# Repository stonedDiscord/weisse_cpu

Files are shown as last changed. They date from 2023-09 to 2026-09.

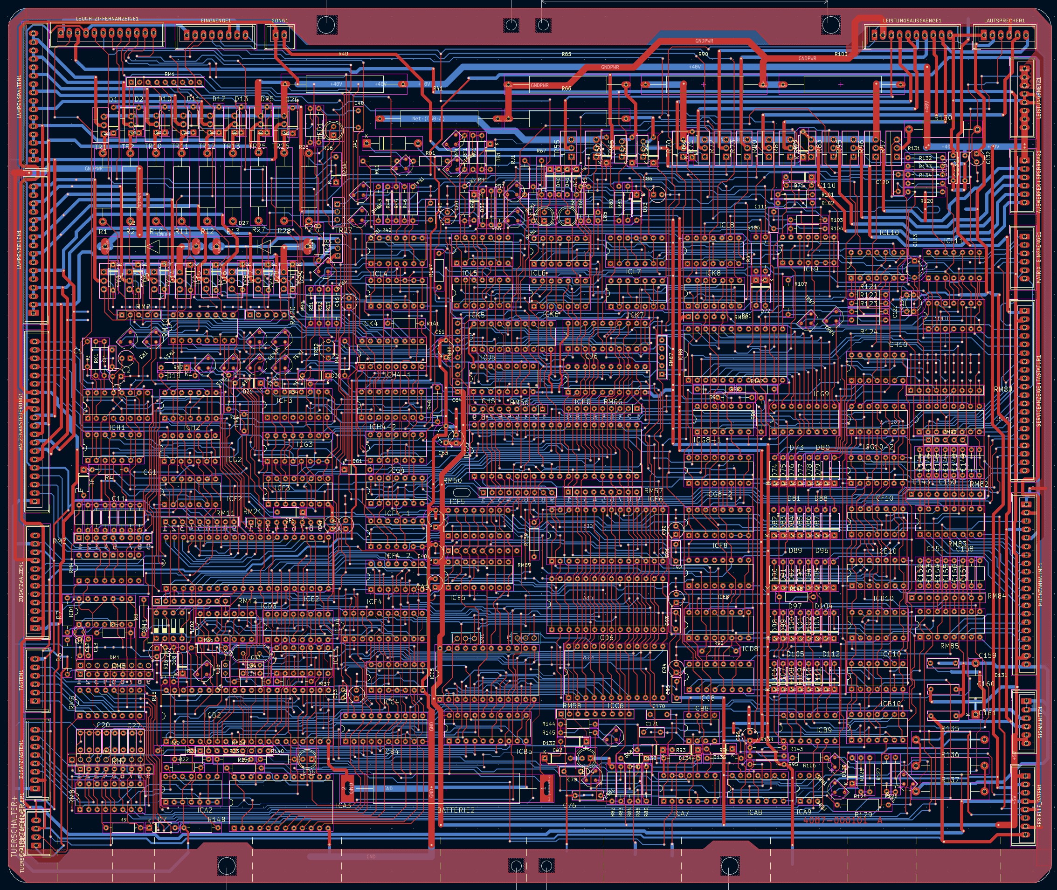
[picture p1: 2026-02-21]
layout_weisse_cpu.jpg

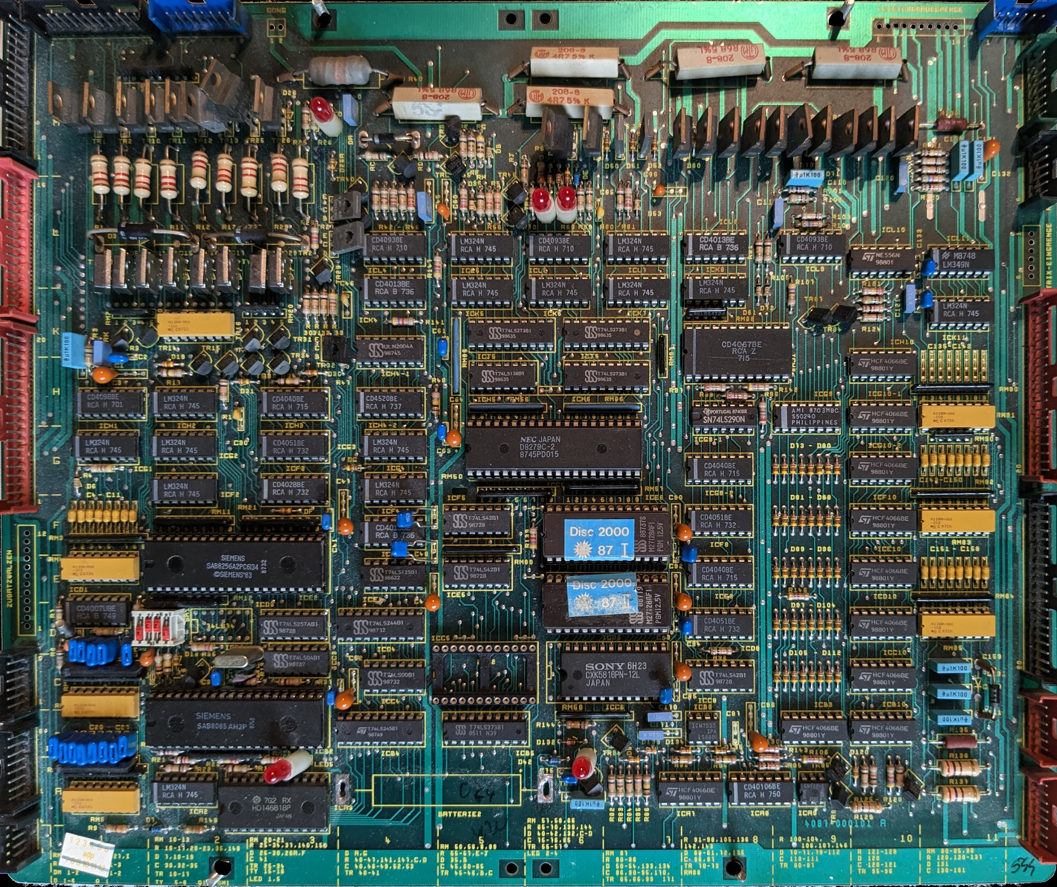
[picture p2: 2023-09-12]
photo/front.jpg

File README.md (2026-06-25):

# Die Weiße CPU

Dies ist ein Reverse-Engineering Projekt fuer die "Elektronische Steuereinheit" von adp.

```mermaid
graph LR
    4087-000101

    subgraph CPU_BLK["CPU"]
        C["8085A\nICB2\n74LS373 addr latch\n74LS245 data buf"]
    end

    subgraph ADEC["Address Decode"]
        D["74LS138 (ICH5)\nmem bank select\n\n74LS42 ×3\nI/O port select"]
    end

    subgraph MMAP["Memory Map"]
        M1["0x0000–0x3FFF\nSocket 1 · ICD6 27128  (16 KB)"]
        M2["0x4000–0x7FFF\nSocket 2 · ICE6 27128  (16 KB)"]
        M3["0x8000–0x8FFF\nSocket 3 · ICC5 2764  (8 KB, empty)"]
        M4["0x9000–0x900F\nRTC · ICA3 HD146818  (16 B, mem-mapped)"]
        M5["0xC000–0xFFFF\nSRAM · ICC6 CY62256  (32 KB chip)"]
    end

    subgraph IOMAP["I/O Map"]
        I1["0x50  8279 data\n0x51  8279 cmd"]
        I2["0x60–6F  8256 regs"]
        I3["0x70  coin ejector\n0x71  sound start\n0x72  tone note\n0x73  PPI ctrl"]
    end

    subgraph EXT["External"]
        E1["16× 7-seg display\nLamp matrix 8×8\nButton/coin matrix 8×8"]
        E2["Serial 4800 8N1\nreel stepper motor\nreel optical sensor"]
        E3["Coin ejector\nTone generator"]
    end

    C <--> D
    D <--> MMAP
    D <--> IOMAP
    I1 --- E1
    I2 --- E2
    I3 --- E3
```

Bei 4040 Platinen sind die IO Adressen anders verteilt:

| IO | Ports |
| ---- | ---|
| 0x70-0x73 | 8255: Auswerfer+Zähler+Sound |
| 0x80-0x81 | 8279: Lampen+Tasten |
| 0x90-0x9f | 8256: Timer+Seriell+Walzen |

Aus diesem Grund sind die Programme nicht mit beiden Platinen kompatibel.
Die Lampen und Timer würden ohne Anpassung nicht funktionieren.

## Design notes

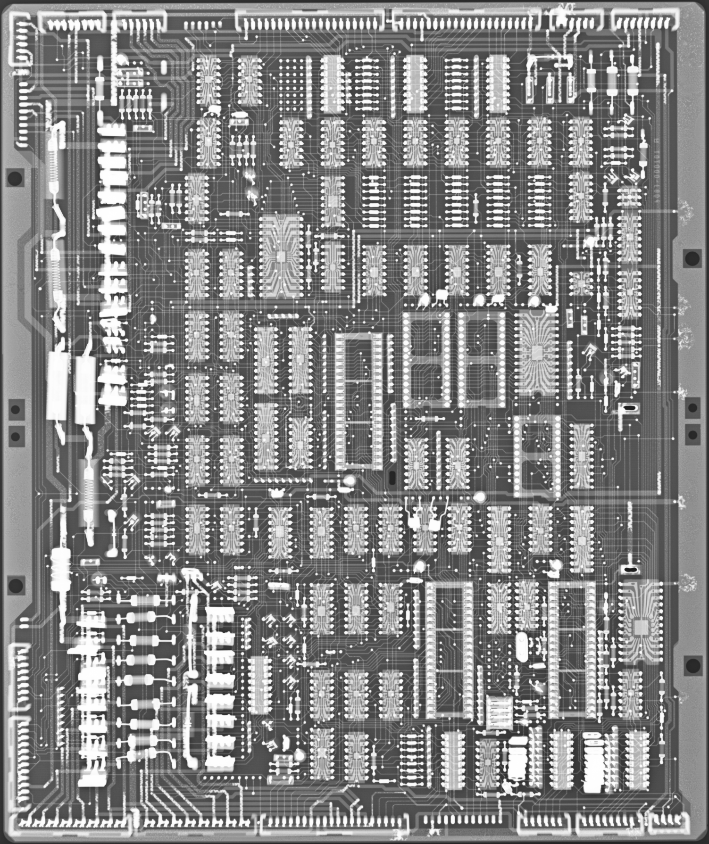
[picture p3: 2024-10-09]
xray.png

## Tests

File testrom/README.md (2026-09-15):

# Testrom

In diesem Ordner ist ein Testrom dass auf ein EPROM gebrannt und in Sockel I auf der Steuereinheit gesteckt werden kann.

Beim Hochfahren startet es einen kurzen Selbsttest der über die serielle Schnittstelle ausgegeben wird.

Danach können über die Fronttasten des Automaten folgende Funktionen gestartet werden:

| Nr | Funktion |
| -- | --- |
| 0  | Reset |
| 1  | Alle Lampen ein |
| 2  | Datum setzen |
| 3  | Musik spielen |
| 4  | Zeit setzen |
| 5  | Alle Lampen aus |
| 6  | Lampentest |
| 7  | Alle Lampen ein |
| 8  | 8256 Test |
| 9  | 8279 Test |
| 10 | RAM Test |
| 11 | RTC Test |
| 12 | Scheiben auslesen |
| 13 | Münzeinwurf aufzeichen |

Die beiden Risikotasten entsprechen links/rechts niedriger/höher und mit der Rückgabetaste kann zurück ins Menü gesprungen werden.

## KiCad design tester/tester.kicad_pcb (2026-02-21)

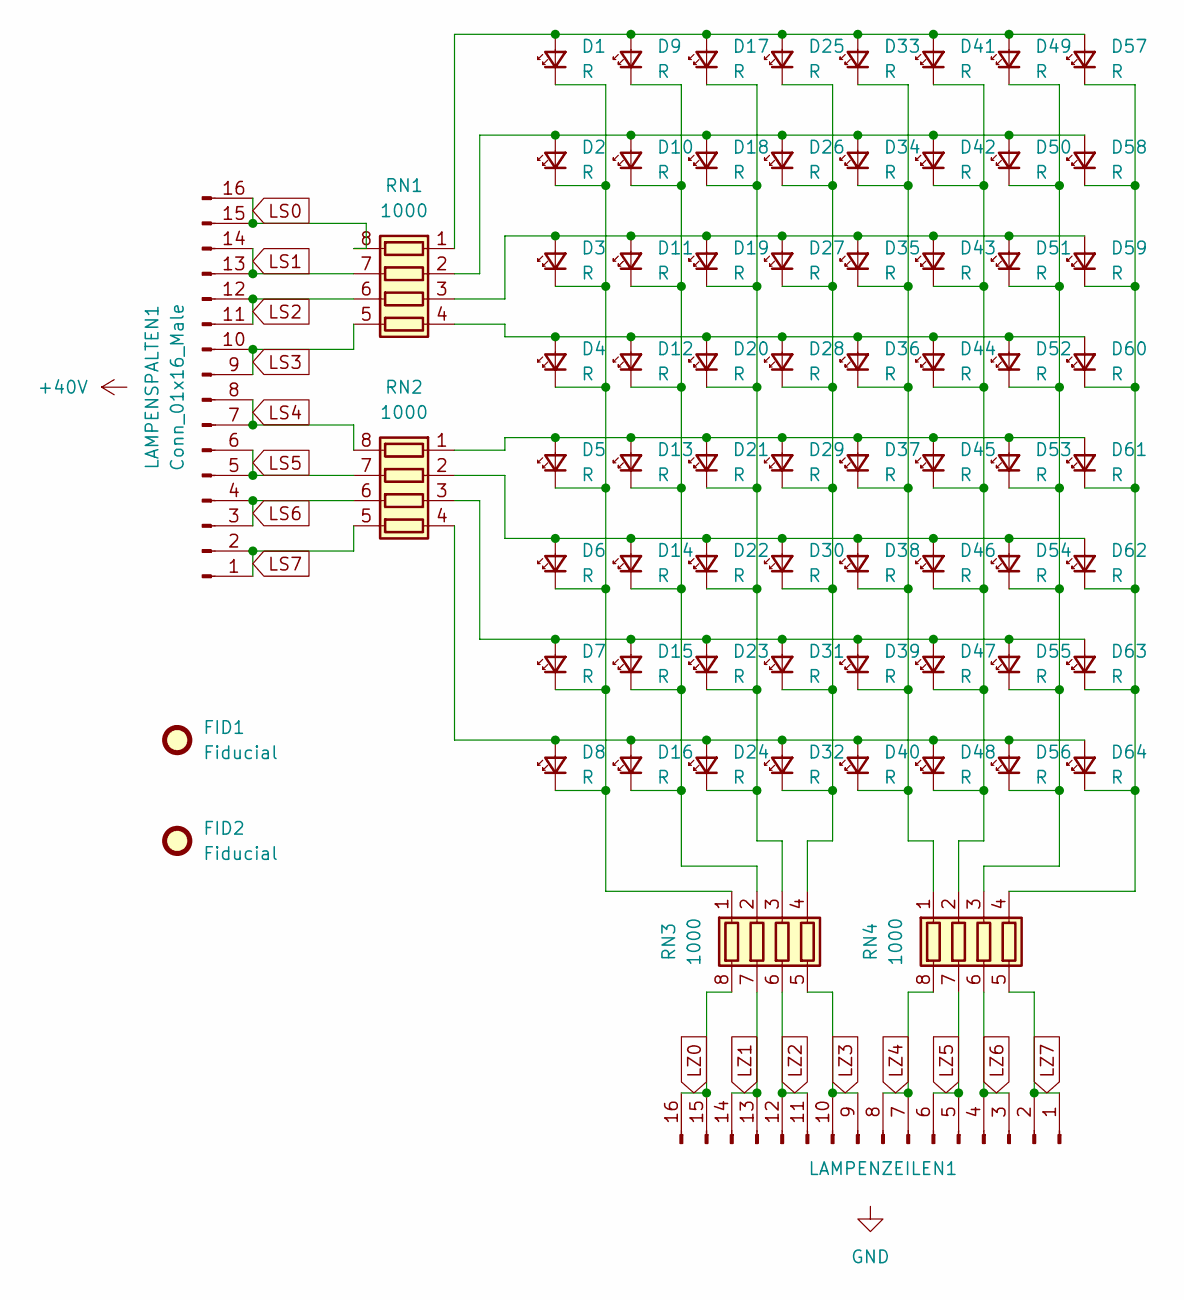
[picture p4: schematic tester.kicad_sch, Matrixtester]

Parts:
D1, D2, D3, D4, D5, D6, D7, D8, D9, D10, D11, D12, D13, D14, D15, D16, D17, D18, D19, D20, D21, D22, D23, D24, D25, D26, D27, D28, D29, D30, D31, D32, D33, D34, D35, D36, D37, D38, D39, D40, D41, D42, D43, D44, D45, D46, D47, D48, D49, D50, D51, D52, D53, D54, D55, D56, D57, D58, D59, D60, D61, D62, D63, D64: R; LED_0603_1608Metric_Pad1.05x0.95mm_HandSolder
FID1: Fiducial; Fiducial_Cross_1.5mm_Mask2mm
FID2: Fiducial; Fiducial_0.5mm_Mask1.5mm
LAMPENSPALTEN1: Conn_01x16_Male; Lumberg_MSF_B16B-MSF-A_1x16_P2.50mm_Vertical
LAMPENZEILEN1: Conn_01x16_Pin; Lumberg_MSF_B16B-MSF-A_1x16_P2.50mm_Vertical
RN1, RN2, RN3, RN4: 1000; R_Array_Concave_4x0603

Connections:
LS0: LAMPENSPALTEN1.15, LAMPENSPALTEN1.16, RN1.8 (R1.2)
LS1: LAMPENSPALTEN1.13, LAMPENSPALTEN1.14, RN1.7 (R2.2)
LS2: LAMPENSPALTEN1.11, LAMPENSPALTEN1.12, RN1.6 (R3.2)
LS3: LAMPENSPALTEN1.9, LAMPENSPALTEN1.10, RN1.5 (R4.2)
LS4: LAMPENSPALTEN1.7, LAMPENSPALTEN1.8, RN2.8 (R1.2)
LS5: LAMPENSPALTEN1.5, LAMPENSPALTEN1.6, RN2.7 (R2.2)
LS6: LAMPENSPALTEN1.3, LAMPENSPALTEN1.4, RN2.6 (R3.2)
LS7: LAMPENSPALTEN1.1, LAMPENSPALTEN1.2, RN2.5 (R4.2)
LZ0: LAMPENZEILEN1.15, LAMPENZEILEN1.16, RN3.8 (R1.2)
LZ1: LAMPENZEILEN1.13, LAMPENZEILEN1.14, RN3.7 (R2.2)
LZ2: LAMPENZEILEN1.11, LAMPENZEILEN1.12, RN3.6 (R3.2)
LZ3: LAMPENZEILEN1.9, LAMPENZEILEN1.10, RN3.5 (R4.2)
LZ4: LAMPENZEILEN1.7, LAMPENZEILEN1.8, RN4.8 (R1.2)
LZ5: LAMPENZEILEN1.5, LAMPENZEILEN1.6, RN4.7 (R2.2)
LZ6: LAMPENZEILEN1.3, LAMPENZEILEN1.4, RN4.6 (R3.2)
LZ7: LAMPENZEILEN1.1, LAMPENZEILEN1.2, RN4.5 (R4.2)
unnamed: D1.2 (A), D9.2 (A), D17.2 (A), D25.2 (A), D33.2 (A), D41.2 (A), D49.2 (A), D57.2 (A), RN1.1 (R1.1)
unnamed: D1.1 (K), D2.1 (K), D3.1 (K), D4.1 (K), D5.1 (K), D6.1 (K), D7.1 (K), D8.1 (K), RN3.1 (R1.1)
unnamed: D2.2 (A), D10.2 (A), D18.2 (A), D26.2 (A), D34.2 (A), D42.2 (A), D50.2 (A), D58.2 (A), RN1.2 (R2.1)
unnamed: D9.1 (K), D10.1 (K), D11.1 (K), D12.1 (K), D13.1 (K), D14.1 (K), D15.1 (K), D16.1 (K), RN3.2 (R2.1)
unnamed: D3.2 (A), D11.2 (A), D19.2 (A), D27.2 (A), D35.2 (A), D43.2 (A), D51.2 (A), D59.2 (A), RN1.3 (R3.1)
unnamed: D4.2 (A), D12.2 (A), D20.2 (A), D28.2 (A), D36.2 (A), D44.2 (A), D52.2 (A), D60.2 (A), RN1.4 (R4.1)
unnamed: D5.2 (A), D13.2 (A), D21.2 (A), D29.2 (A), D37.2 (A), D45.2 (A), D53.2 (A), D61.2 (A), RN2.1 (R1.1)
unnamed: D6.2 (A), D14.2 (A), D22.2 (A), D30.2 (A), D38.2 (A), D46.2 (A), D54.2 (A), D62.2 (A), RN2.2 (R2.1)
unnamed: D7.2 (A), D15.2 (A), D23.2 (A), D31.2 (A), D39.2 (A), D47.2 (A), D55.2 (A), D63.2 (A), RN2.3 (R3.1)
unnamed: D8.2 (A), D16.2 (A), D24.2 (A), D32.2 (A), D40.2 (A), D48.2 (A), D56.2 (A), D64.2 (A), RN2.4 (R4.1)
unnamed: D17.1 (K), D18.1 (K), D19.1 (K), D20.1 (K), D21.1 (K), D22.1 (K), D23.1 (K), D24.1 (K), RN3.3 (R3.1)
unnamed: D25.1 (K), D26.1 (K), D27.1 (K), D28.1 (K), D29.1 (K), D30.1 (K), D31.1 (K), D32.1 (K), RN3.4 (R4.1)
unnamed: D33.1 (K), D34.1 (K), D35.1 (K), D36.1 (K), D37.1 (K), D38.1 (K), D39.1 (K), D40.1 (K), RN4.1 (R1.1)
unnamed: D41.1 (K), D42.1 (K), D43.1 (K), D44.1 (K), D45.1 (K), D46.1 (K), D47.1 (K), D48.1 (K), RN4.2 (R2.1)
unnamed: D49.1 (K), D50.1 (K), D51.1 (K), D52.1 (K), D53.1 (K), D54.1 (K), D55.1 (K), D56.1 (K), RN4.3 (R3.1)
unnamed: D57.1 (K), D58.1 (K), D59.1 (K), D60.1 (K), D61.1 (K), D62.1 (K), D63.1 (K), D64.1 (K), RN4.4 (R4.1)

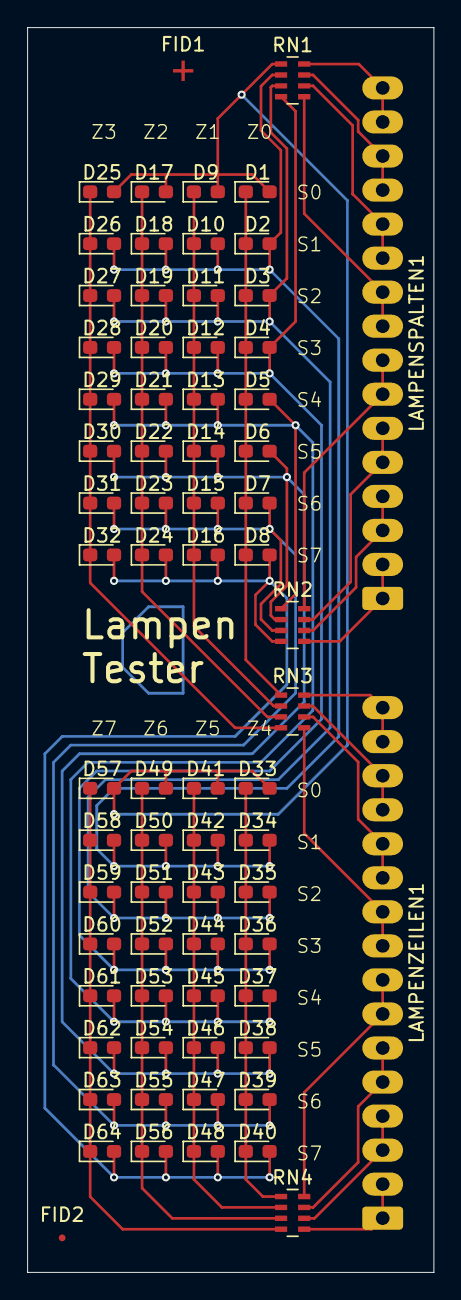
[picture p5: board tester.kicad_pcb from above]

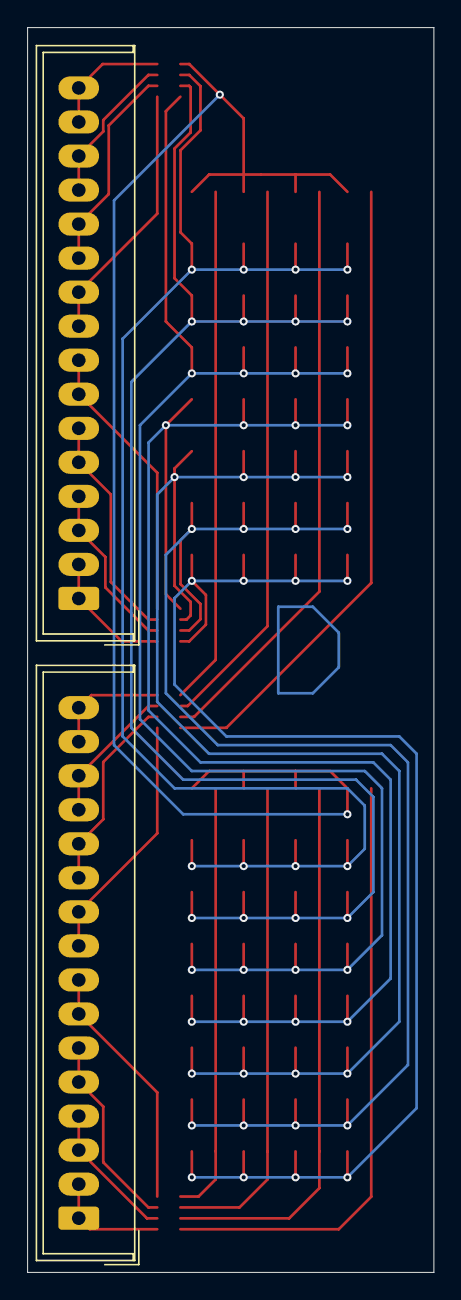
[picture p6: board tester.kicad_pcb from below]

Board: 2 copper layers, 29.8 x 91.4 mm, 72 parts (2 on the bottom side), 32 nets.

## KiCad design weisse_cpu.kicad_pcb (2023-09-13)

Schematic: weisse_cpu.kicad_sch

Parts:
AUSWERFER+SPERRMAG1: Conn_01x06_Pin; PinHeader_1x06_P2.54mm_Vertical
BATTERIE2: Battery_Cell; Batterie
C1, C76, C110, C130, C131, C159, C160, C161: C; C_Rect_L9.0mm_W2.5mm_P7.50mm_MKT
C2, C3, C49: C; CP_Radial_Tantal_D4.5mm_P2.50mm
C4, C5, C6, C7, C8, C9, C10, C11, C143, C144, C145, C146, C147, C148, C149, C150, C151, C152, C153, C154, C155, C156, C157, C158: C; C_Axial_L3.8mm_D2.6mm_P7.50mm_Horizontal
C20, C21, C22, C23, C24, C25, C26, C27: C; C_Rect_L7.0mm_W2.0mm_P5.00mm
C48: C; CP_Radial_Tantal_D4.5mm_P5.00mm
D1, D2, D4, D5, D6, D7, D8, D10, D11, D12, D13, D14, D15, D16, D17, D18, D19, D25, D26, D28, D29, D50, D51, D52, D73, D74, D75, D76, D77, D78, D79, D80, D81, D82, D83, D84, D85, D86, D87, D88, D89, D90, D91, D92, D93, D94, D95, D96, D97, D98, D99, D100, D101, D102, D103, D104, D105, D106, D107, D108, D109, D110, D111, D112: D; D_A-405_P7.62mm_Horizontal
D3, D27: D; BigDiode
DM1, DM2: DAN_801; SIP9_Housing
EINGAENGE1: Conn_01x08_Male; PinHeader_1x08_P2.54mm_Vertical
GONG1: Conn_01x02_Pin; PinHeader_1x02_P2.54mm_Vertical; not fitted
ICA2: LM324; DIP-14_W7.62mm
ICA3: PAL20L8; DIP-24_W15.24mm
ICA7: 4066; DIP-14_W7.62mm
ICA8: 40106; DIP-14_W7.62mm
ICA9: CNY17-1; DIP-6_W7.62mm
ICB2: 8085; DIP-40_W15.24mm
ICB4: 74LS245; DIP-20_W7.62mm
ICB5: 74LS373; DIP-20_W7.62mm
ICB8: ICM7555xP; DIP-8_W7.62mm
ICB9, ICB10: 4066; DIP-14_W7.62mm
ICC3: 74LS04; DIP-14_W7.62mm
ICC4: 74LS00; DIP-14_W7.62mm
ICC5: 2764; DIP-24_W15.24mm
ICC6: CXK5816PN-12L; DIP-24_W15.24mm
ICC8: 74LS42; DIP-16_W7.62mm
ICC10: 4066; DIP-14_W7.62mm
ICD3: 74LS257; DIP-16_W7.62mm
ICD4: 74LS244; DIP-20_W7.62mm
ICD6: 27128; DIP-28_W15.24mm
ICD8: CD4051B; DIP-16_W7.62mm
ICD10: 4066; DIP-14_W7.62mm
ICE2: 8256; DIP-40_W15.24mm
ICE4: 74125; DIP-14_W7.62mm
ICE5: 74LS42; DIP-16_W7.62mm
ICE6: 27128; DIP-28_W15.24mm
ICE10: 4066; DIP-14_W7.62mm
ICF2: LM324; DIP-14_W7.62mm
ICF3: 4028; DIP-16_W7.62mm
ICF4-2: 4013; DIP-14_W7.62mm
ICF5: 74LS42; DIP-16_W7.62mm
ICF8: CD4051B; DIP-16_W7.62mm
ICF10: 4066; DIP-14_W7.62mm
ICG1, ICG2, ICG4, ICG4-1: LM324; DIP-14_W7.62mm
ICG3: 4051; DIP-16_W7.62mm
ICG5: DIP-40_W15.24mm
ICG8-1: 74LS290; DIP-14_W7.62mm
ICG8-2: 4040; DIP-16_W7.62mm
ICG9: DIP-16_W7.62mm
ICG10-1, ICG10-2: 4066; DIP-14_W7.62mm
ICH1: 4098; DIP-16_W7.62mm
ICH2: LM324; DIP-14_W7.62mm
ICH3: 4040; DIP-16_W7.62mm
ICH4-1: ULN2004A; DIP-16_W7.62mm
ICH4-2: 4520; DIP-16_W7.62mm
ICH5: 74LS138; DIP-16_W7.62mm
ICH6: 74AHC273; DIP-20_W7.62mm
ICH8: CD74HC4067M; SOIC-24W_7.5x15.4mm_P1.27mm
ICH10: 4066; DIP-14_W7.62mm
ICJ5, ICJ6: 74AHC273; DIP-20_W7.62mm
ICK4: 4013; DIP-14_W7.62mm
ICK5, ICK6, ICK7, ICK8, ICK11: LM324; DIP-14_W7.62mm
ICL4, ICL6, ICL9: 4093; DIP-14_W7.62mm
ICL5, ICL7: LM324; DIP-14_W7.62mm
ICL8: 4013; DIP-14_W7.62mm
ICL10: NE556; DIP-14_W7.62mm
ICL11: Opamp_Quad; DIP-14_W7.62mm
LAMPENSPALTEN1: Conn_01x16_Male; PinHeader_1x16_P2.54mm_Vertical
LAMPENZEILEN1: Conn_01x16_Pin; PinHeader_1x16_P2.54mm_Vertical
LAUTSPRECHER1: Conn_01x06_Pin; PinHeader_1x06_P2.54mm_Vertical
LED1, LED2, LED3, LED4, LED5: LED; LED_D5.0mm
LEISTUNGSAUSGAENGE1: Conn_01x10_Pin; PinHeader_1x10_P2.54mm_Vertical; not fitted
LEISTUNGSNETZ1: Conn_01x08_Male; PinHeader_1x08_P2.54mm_Vertical
LEUCHTZIFFERNANZEIGE1: Conn_01x12_Pin; PinHeader_1x12_P2.54mm_Vertical
MATRIX-EINGAENGE1: Conn_01x06_Pin; PinHeader_1x06_P2.54mm_Vertical; not fitted
MUENZANNAHME1: Conn_01x20_Pin; PinHeader_1x20_P2.54mm_Vertical
Q1: Crystal; Crystal_AT310_D3.0mm_L10.0mm_Vertical
Q2: Crystal; Crystal_HC18-U_Vertical
R1, R2, R10, R11, R12, R13, R27, R28, R29: 1,2k 5%; R_Axial_DIN0414_L11.9mm_D4.5mm_P20.32mm_Horizontal
R3, R17: R; R_Axial_DIN0204_L3.6mm_D1.6mm_P7.62mm_Horizontal
R4, R5, R6, R7: R; R_Axial_DIN0207_L6.3mm_D2.5mm_P10.16mm_Horizontal
R15, R20, R21, R123: 1 kΩ ±5%; R_Axial_DIN0207_L6.3mm_D2.5mm_P10.16mm_Horizontal
R16, R86, R150: 100 kΩ ±5%; R_Axial_DIN0207_L6.3mm_D2.5mm_P10.16mm_Horizontal
R22, R84, R124: 10 kΩ ±5%; R_Axial_DIN0207_L6.3mm_D2.5mm_P10.16mm_Horizontal
R23: 320 kΩ ±5%; R_Axial_DIN0207_L6.3mm_D2.5mm_P10.16mm_Horizontal
R40: 15 2%; BigResistor
R41, R65, R66, R90, R100: R; BigResistor
R82: 3 kΩ ±5%; R_Axial_DIN0207_L6.3mm_D2.5mm_P10.16mm_Horizontal
R83: 180 Ω ±5%; R_Axial_DIN0207_L6.3mm_D2.5mm_P10.16mm_Horizontal
R85: 27 kΩ ±5%; R_Axial_DIN0207_L6.3mm_D2.5mm_P10.16mm_Horizontal
R121: 220 kΩ ±5%; R_Axial_DIN0207_L6.3mm_D2.5mm_P10.16mm_Horizontal
R122: 1 MΩ ±5%; R_Axial_DIN0207_L6.3mm_D2.5mm_P10.16mm_Horizontal
R129: 1 kΩ ±5%; R_Axial_DIN0309_L9.0mm_D3.2mm_P15.24mm_Horizontal
R130: 51; R_Axial_DIN0414_L11.9mm_D4.5mm_P20.32mm_Horizontal
R135: 100 ±5%; R_Axial_DIN0414_L11.9mm_D4.5mm_P20.32mm_Horizontal
R136, R137: 200 Ω ±5%; R_Axial_DIN0414_L11.9mm_D4.5mm_P20.32mm_Horizontal
R140: 220 Ω ±5%; R_Axial_DIN0207_L6.3mm_D2.5mm_P10.16mm_Horizontal
R148: 3,3M 5%; R_Axial_DIN0207_L6.3mm_D2.5mm_P10.16mm_Horizontal
RM2, RM20: R_Network04; R_Array_SIP5
RM3, RM5, RM7, RM11, RM12, RM13, RM21, RM50, RM56, RM57, RM58, RM66, RM80, RM82, RM84: R_Network08; R_Array_SIP9
RM4, RM6, RM8, RM10, RM81, RM83, RM85: R_Pack08; DIP-16_W7.62mm
RN1: R_Network08; R_Array_SIP9
SERIELLE_DATEN1: Conn_01x08_Pin; PinHeader_1x08_P2.54mm_Vertical
SERVICEANZEIGE+TASTATUR1: Conn_01x20_Male; PinHeader_1x20_P2.54mm_Vertical
SIGNALNETZ1: Conn_01x06_Male; PinHeader_1x06_P2.54mm_Vertical
SW1: SW_DIP_x04; SW_DIP_SPSTx04_Slide_9.78x12.34mm_W7.62mm_P2.54mm
TASTEN1: Conn_01x06_Pin; PinHeader_1x06_P2.54mm_Vertical
TR1, TR2, TR10, TR11, TR12, TR25, TR26: BDX34B; TO-220-3_Vertical
TR3, TR14, TR15, TR16, TR30, TR31, TR33, TR34, TR85: BC237; TO-92_Inline
TR13: BDX54C; TO-220-3_Vertical
TR27: BD140; TO-126-3_Vertical
TR29, TR65, TR66: BD139; TO-126-3_Vertical
TR32: BD679; TO-126-3_Vertical
TR40: BC557; TO-92_Inline
TR55, TR56, TR70, TR71, TR72, TR73, TR80, TR81, TR82, TR83, TR95, TR96, TR97: Q_NPN_Darlington_BCE; TO-220-3_Vertical
TR84, TR87: NMOS; BigTransistor
TR86: BC327; TO-92_Inline
TUERSCHALTER+SPIELZAEHLER1: Conn_01x04_Pin; PinHeader_1x04_P2.54mm_Vertical
TY1, TY2, TY5, TY6, TY7, TY8, TY15, TY16: TIC126; TO-220-3_Vertical
WALZENANSTEUERUNG1: Conn_01x20_Pin; PinHeader_1x20_P2.54mm_Vertical
ZUSATZTASTEN1: Conn_01x08_Pin; PinHeader_1x08_P2.54mm_Vertical
ZUSATZWALZEN1: Conn_01x12_Pin; PinHeader_1x12_P2.54mm_Vertical; not fitted

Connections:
+5V: LEUCHTZIFFERNANZEIGE1.3, SERIELLE_DATEN1.1, SERVICEANZEIGE+TASTATUR1.2, SIGNALNETZ1.5, SIGNALNETZ1.6
+12V: C161.1, EINGAENGE1.1, LAUTSPRECHER1.2, LEUCHTZIFFERNANZEIGE1.4, MUENZANNAHME1.4, SERIELLE_DATEN1.8, SIGNALNETZ1.4, TASTEN1.6, TUERSCHALTER+SPIELZAEHLER1.3, ZUSATZTASTEN1.2
+15V: SIGNALNETZ1.3
+24V: LAUTSPRECHER1.1, LEISTUNGSAUSGAENGE1.10, LEISTUNGSNETZ1.4, LEISTUNGSNETZ1.5, MUENZANNAHME1.2, SERIELLE_DATEN1.4, WALZENANSTEUERUNG1.12
+48V: AUSWERFER+SPERRMAG1.1, EINGAENGE1.6, GONG1.1, LEISTUNGSNETZ1.6, LEISTUNGSNETZ1.7, LEISTUNGSNETZ1.8, R40.2, SERIELLE_DATEN1.2, TUERSCHALTER+SPIELZAEHLER1.4, WALZENANSTEUERUNG1.14
A0: ICB5.2 (O0), ICC5.8 (A0), ICC6.8 (A0), ICD6.10 (A0), ICE6.10 (A0), RM58.9 (R8)
A1: ICB5.5 (O1), ICC5.7 (A1), ICC6.7 (A1), ICD6.9 (A1), ICE6.9 (A1), RM58.8 (R7)
A2: ICB5.6 (O2), ICC5.6 (A2), ICC6.6 (A2), ICD6.8 (A2), ICE6.8 (A2), RM58.7 (R6)
A3: ICB5.9 (O3), ICC5.5 (A3), ICC6.5 (A3), ICD6.7 (A3), ICE6.7 (A3), RM58.6 (R5)
A4: ICB5.12 (O4), ICC5.4 (A4), ICC6.4 (A4), ICD6.6 (A4), ICE6.6 (A4), RM58.5 (R4)
A5: ICB5.15 (O5), ICC5.3 (A5), ICC6.3 (A5), ICD6.5 (A5), ICE6.5 (A5), RM58.4 (R3)
A6: ICB5.16 (O6), ICC5.2 (A6), ICC6.2 (A6), ICD6.4 (A6), ICE6.4 (A6), RM58.3 (R2)
A7: ICB5.19 (O7), ICC5.1 (A7), ICC6.1 (A7), ICD6.3 (A7), ICE6.3 (A7), RM58.2 (R1)
A8: ICC5.23 (A8), ICC6.23 (A8), ICD6.25 (A8), ICE6.25 (A8), RM57.2 (R1)
A9: ICC5.22 (A9), ICC6.22 (A9), ICD6.24 (A9), ICE6.24 (A9), RM57.3 (R2)
A10: ICC5.19 (A10), ICC6.19 (A10), ICD6.21 (A10), ICE6.21 (A10), RM57.6 (R5)
A11: ICC5.21 (A11), ICD6.23 (A11), ICE6.23 (A11), RM57.4 (R3)
A12: ICD6.2 (A12), ICE6.2 (A12)
A13: ICD6.26 (A13), ICE6.26 (A13)
AD0: ICB2.12 (AD0), ICB4.2 (A0), ICB5.3 (D0)
AD1: ICB2.13 (AD1), ICB4.3 (A1), ICB5.4 (D1)
AD2: ICB2.14 (AD2), ICB4.4 (A2), ICB5.7 (D2)
AD3: ICB2.15 (AD3), ICB4.5 (A3), ICB5.8 (D3)
AD4: ICB2.16 (AD4), ICB4.6 (A4), ICB5.13 (D4)
AD5: ICB2.17 (AD5), ICB4.7 (A5), ICB5.14 (D5)
AD6: ICB2.18 (AD6), ICB4.8 (A6), ICB5.17 (D6)
AD7: ICB2.19 (AD7), ICB4.9 (A7), ICB5.18 (D7)
D0: ICB4.18 (B0), ICC5.9 (D0), ICC6.9 (I/O1), ICD6.11 (D0), ICE6.11 (D0), ICG5.12 (DB0)
D1: ICB4.17 (B1), ICC5.10 (D1), ICC6.10 (I/O2), ICD6.12 (D1), ICE6.12 (D1), ICG5.13 (DB1)
D2: ICB4.16 (B2), ICC5.11 (D2), ICC6.11 (I/O3), ICD6.13 (D2), ICE6.13 (D2), ICG5.14 (DB2)
D3: ICB4.15 (B3), ICC5.13 (D3), ICC6.13 (I/O4), ICD6.15 (D3), ICE6.15 (D3), ICG5.15 (DB3)
D4: ICB4.14 (B4), ICC5.14 (D4), ICC6.14 (I/O5), ICD6.16 (D4), ICE6.16 (D4), ICG5.16 (DB4), RM57.5 (R4)
D5: ICB4.13 (B5), ICC5.15 (D5), ICC6.15 (I/O6), ICD6.17 (D5), ICE6.17 (D5), ICG5.17 (DB5), RM57.7 (R6)
D6: ICB4.12 (B6), ICC5.16 (D6), ICC6.16 (I/O7), ICD6.18 (D6), ICE6.18 (D6), ICG5.18 (DB6), RM57.9 (R8)
D7: ICB4.11 (B7), ICC5.17 (D7), ICC6.17 (I/O8), ICD6.19 (D7), ICE6.19 (D7), ICG5.19 (DB7), RM57.8 (R7)
GND: C159.2, C160.2, C161.2, D73.1 (K), D74.1 (K), D75.1 (K), D76.1 (K), D77.1 (K), D78.1 (K), D79.1 (K), D80.1 (K), EINGAENGE1.7, ICB5.10 (GND), ICB9.7 (VSS), ICB10.7 (VSS), ICC3.7 (GND), ICC4.7 (GND), ICC6.12 (GND), ICC10.7 (VSS), ICD3.8 (GND), ICD6.14 (GND), ICD10.7 (VSS), ICE6.14 (GND), ICE10.7 (VSS), ICF10.7 (VSS), ICG5.20 (Vss), ICG8-1.7 (GND), ICG8-2.8 (VSS), ICG9.1 (Vss), ICG10-1.14 (VDD), ICG10-2.7 (VSS), ICH1.8 (VSS), ICH8.12 (GND), ICH10.7 (VSS), ICK11.11 (V-), ICL8.7 (VSS), ICL9.5, ICL9.6, ICL9.7 (Vss), ICL10.7 (GND), LEUCHTZIFFERNANZEIGE1.1, R137.1, SERVICEANZEIGE+TASTATUR1.1, SIGNALNETZ1.1, SIGNALNETZ1.2, WALZENANSTEUERUNG1.1, ZUSATZTASTEN1.1
GNDPWR: LAUTSPRECHER1.4, LEISTUNGSAUSGAENGE1.2, LEISTUNGSNETZ1.1, LEISTUNGSNETZ1.2, LEISTUNGSNETZ1.3, MUENZANNAHME1.1, R41.2, R65.1, R66.1, R90.2, R100.1, SERIELLE_DATEN1.7, WALZENANSTEUERUNG1.13
unnamed: C76.2, R82.1, R83.1
unnamed: D1.2 (A), D2.2 (A), D10.2 (A), D11.2 (A), D12.2 (A), D13.2 (A), D25.2 (A), D26.2 (A)
unnamed: D1.1 (K), D2.1 (K), D10.1 (K), D11.1 (K), D12.1 (K), D13.1 (K), D25.1 (K), D26.1 (K), R40.1, RN1.1 (common), TR1.3 (E), TR2.3 (E), TR10.3 (E), TR11.3 (E), TR12.3 (E), TR13.3 (E), TR25.3 (E), TR26.3 (E)
unnamed: D4.2 (A), LAMPENZEILEN1.15, LAMPENZEILEN1.16, TY1.2 (A)
unnamed: D5.2 (A), LAMPENZEILEN1.13, LAMPENZEILEN1.14, TY2.2 (A)
unnamed: C4.2, C5.2, C6.2, C7.2, C8.2, C9.2, C10.2, C11.2, D6.2 (A)
unnamed: D6.1 (K), R4.2
unnamed: D7.2 (A), ICA2.3 (+), R148.1
unnamed: D8.2 (A), LED4.2 (A)
unnamed: D14.2 (A), LAMPENZEILEN1.11, LAMPENZEILEN1.12, TY5.2 (A)
unnamed: D4.1 (K), D5.1 (K), D14.1 (K), D15.1 (K), D16.1 (K), D17.1 (K), D28.1 (K), D29.1 (K), TR29.2 (C)
unnamed: D15.2 (A), LAMPENZEILEN1.9, LAMPENZEILEN1.10, TY6.2 (A)
unnamed: D16.2 (A), LAMPENZEILEN1.7, LAMPENZEILEN1.8, TY7.2 (A)
unnamed: D17.2 (A), LAMPENZEILEN1.5, LAMPENZEILEN1.6, TY8.2 (A)
unnamed: D18.2 (A), R16.2
unnamed: D3.1 (K), D27.1 (K), TR29.1 (E)
unnamed: D28.2 (A), LAMPENZEILEN1.3, LAMPENZEILEN1.4, TY15.2 (A)
unnamed: D29.2 (A), LAMPENZEILEN1.1, LAMPENZEILEN1.2, TY16.2 (A)
unnamed: D50.2 (A), R41.1, TR55.3 (E), TR56.3 (E)
unnamed: D51.2 (A), TR65.3 (B)
unnamed: D52.2 (A), TR66.3 (B)
unnamed: D85.1 (K), D86.1 (K), D87.1 (K), D88.1 (K)
unnamed: D89.1 (K), D90.1 (K), D91.1 (K), D92.1 (K), D93.1 (K), D94.1 (K), D95.1 (K), D96.1 (K)
unnamed: D97.1 (K), D98.1 (K), D99.1 (K), D100.1 (K), D102.1 (K), D103.1 (K), D104.1 (K)
unnamed: D105.1 (K), D106.1 (K), D107.1 (K), D108.1 (K), D110.1 (K), D111.1 (K)
unnamed: ICA2.5 (+), R148.2
unnamed: ICB2.1 (X1), R20.1
unnamed: ICC4.3, ICC4.4, ICC4.5
unnamed: ICE2.32 (P1.7), RM11.3 (R2)
unnamed: ICE2.31 (P2.0), RM11.4 (R3)
unnamed: ICE2.30 (P2.1), RM11.5 (R4)
unnamed: ICE2.29 (P2.2), RM21.2 (R1)
unnamed: ICE2.28 (P2.3), RM21.3 (R2)
unnamed: ICE2.27 (P2.4), RM21.4 (R3)
unnamed: ICE2.26 (P2.5), RM21.5 (R4)
unnamed: ICE2.25 (P2.6), RM21.6 (R5)
unnamed: ICE2.24 (P2.7), RM21.7 (R6)
unnamed: ICF2.14, R4.1
unnamed: ICF2.3 (+), RM11.6 (R5)
unnamed: ICF2.2 (-), ICF2.6 (-)
unnamed: ICF2.5 (+), RM11.7 (R6)
unnamed: ICG1.2 (-), ICG1.6 (-), ICG2.2 (-), ICG2.6 (-)
unnamed: ICG4.2 (-), ICG4.6 (-)
unnamed: ICG4.10 (+), ICG5.29 (OUT_B2)
unnamed: ICG9.15 (÷_239), ICH8.8 (I1)
unnamed: ICG9.14 (÷_253), ICH8.7 (I2)
unnamed: ICG9.13 (÷_268), ICH8.6 (I3)
unnamed: ICG9.12 (÷_284), ICH8.5 (I4)
unnamed: ICG9.11 (÷_301), ICH8.4 (I5)
unnamed: ICG9.10 (÷_319), ICH8.3 (I6)
unnamed: ICG9.9 (÷_338), ICH8.2 (I7)
unnamed: ICG9.8 (÷_358), ICH8.23 (I8)
unnamed: ICG9.7 (÷_379), ICH8.22 (I9)
unnamed: ICG9.6 (÷_402), ICH8.21 (I10)
unnamed: ICG9.5 (÷_426), ICH8.20 (I11)
unnamed: ICG9.4 (÷_451), ICH8.19 (I12)
unnamed: ICG9.16 (÷_478), ICH8.9 (I0)
unnamed: ICH4-1.16 (O1), R2.1
unnamed: ICH4-1.15 (O2), R10.1
unnamed: ICH4-1.14 (O3), R11.1
unnamed: ICH4-1.13 (O4), R12.1
unnamed: ICH4-1.12 (O5), R13.1
unnamed: ICH4-1.11 (O6), R27.1
unnamed: ICH4-1.10 (O7), R28.1
unnamed: ICH6.5 (Q1), RM56.4 (R3)
unnamed: ICH6.6 (Q2), RM56.3 (R2)
unnamed: ICH6.9 (Q3), RM56.2 (R1)
unnamed: ICL9.8, ICL9.9
unnamed: ICL10.2 (THR), ICL10.6 (TR)
unnamed: ICL11.10 (+), ICL11.12 (+)
unnamed: LAMPENSPALTEN1.1, LAMPENSPALTEN1.2, TR26.2 (C)
unnamed: LAMPENSPALTEN1.3, LAMPENSPALTEN1.4, TR25.2 (C)
unnamed: LAMPENSPALTEN1.5, LAMPENSPALTEN1.6, TR13.2 (C)
unnamed: LAMPENSPALTEN1.7, LAMPENSPALTEN1.8, TR12.2 (C)
unnamed: LAMPENSPALTEN1.9, LAMPENSPALTEN1.10, TR11.2 (C)
unnamed: LAMPENSPALTEN1.11, LAMPENSPALTEN1.12, TR10.2 (C)
unnamed: LAMPENSPALTEN1.13, LAMPENSPALTEN1.14, TR2.2 (C)
unnamed: LAMPENSPALTEN1.15, LAMPENSPALTEN1.16, TR1.2 (C)
unnamed: LED4.1 (K), R82.2
unnamed: LED5.1 (K), R140.2
unnamed: MUENZANNAHME1.6, RM83.8 (R8.1)
unnamed: MUENZANNAHME1.7, RM83.7 (R7.1)
unnamed: MUENZANNAHME1.8, RM83.6 (R6.1)
unnamed: MUENZANNAHME1.9, RM83.5 (R5.1)
unnamed: MUENZANNAHME1.10, RM83.4 (R4.1)
unnamed: MUENZANNAHME1.11, RM83.3 (R3.1)
unnamed: MUENZANNAHME1.12, RM83.2 (R2.1)
unnamed: MUENZANNAHME1.13, RM83.1 (R1.1)
unnamed: MUENZANNAHME1.14, RM85.4 (R4.1)
unnamed: MUENZANNAHME1.15, RM85.5 (R5.1)
unnamed: MUENZANNAHME1.16, RM85.6 (R6.1)
unnamed: MUENZANNAHME1.17, RM85.7 (R7.1)
unnamed: MUENZANNAHME1.18, RM85.8 (R8.1)
unnamed: R22.2, R23.2
unnamed: R84.1, R85.1
unnamed: R135.1, R136.1
unnamed: R136.2, R137.2
unnamed: C5.1, RM3.2 (R1), RM4.15 (R2.2)
unnamed: C6.1, RM3.3 (R2)
unnamed: C7.1, RM3.4 (R3)
unnamed: C8.1, RM3.5 (R4)
unnamed: C11.1, RM3.8 (R7)
unnamed: RM4.14 (R3.2), WALZENANSTEUERUNG1.2
unnamed: RM4.13 (R4.2), WALZENANSTEUERUNG1.3
unnamed: RM4.12 (R5.2), WALZENANSTEUERUNG1.4
unnamed: RM6.2 (R2.1), TASTEN1.1
unnamed: RM6.3 (R3.1), TASTEN1.2
unnamed: RM6.4 (R4.1), TASTEN1.3
unnamed: RM6.5 (R5.1), TASTEN1.4
unnamed: RM8.14 (R3.2), ZUSATZTASTEN1.6
unnamed: RM8.10 (R7.2), ZUSATZTASTEN1.5
unnamed: RM11.9 (R8), RM21.1 (common)
unnamed: DM2.5, R20.2, R21.2, RM13.1 (common)
unnamed: RM81.1 (R1.1), SERVICEANZEIGE+TASTATUR1.10
unnamed: RM81.2 (R2.1), SERVICEANZEIGE+TASTATUR1.9
unnamed: RM81.3 (R3.1), SERVICEANZEIGE+TASTATUR1.8
unnamed: RM81.4 (R4.1), SERVICEANZEIGE+TASTATUR1.7
unnamed: RM81.5 (R5.1), SERVICEANZEIGE+TASTATUR1.11
unnamed: RM81.6 (R6.1), SERVICEANZEIGE+TASTATUR1.12
unnamed: ICG10-1.5, RM81.11 (R6.2)
unnamed: RM81.7 (R7.1), SERVICEANZEIGE+TASTATUR1.13
unnamed: ICG10-1.12, RM81.10 (R7.2)
unnamed: RM81.8 (R8.1), SERVICEANZEIGE+TASTATUR1.14
unnamed: ICG10-1.6, RM81.9 (R8.2)
unnamed: C143.1, RM82.2 (R1)
unnamed: C144.1, RM82.3 (R2)
unnamed: C145.1, RM82.4 (R3)
unnamed: C146.1, RM82.5 (R4)
unnamed: C147.1, RM82.6 (R5)
unnamed: C148.1, RM82.7 (R6)
unnamed: C149.1, RM82.8 (R7)
unnamed: C150.1, RM82.9 (R8)
unnamed: C151.1, RM84.2 (R1)
unnamed: C152.1, RM84.3 (R2)
unnamed: C153.1, RM84.4 (R3)
unnamed: C154.1, RM84.5 (R4)
unnamed: C155.1, RM84.6 (R5)
unnamed: C156.1, RM84.7 (R6)
unnamed: C157.1, RM84.8 (R7)
unnamed: C158.1, RM84.9 (R8)
unnamed: ICK11.1, SERVICEANZEIGE+TASTATUR1.3
unnamed: ICK11.7, SERVICEANZEIGE+TASTATUR1.4
unnamed: R1.2, TR1.1 (B)
unnamed: R2.2, TR2.1 (B)
unnamed: R10.2, TR10.1 (B)
unnamed: R11.2, TR11.1 (B)
unnamed: R12.2, TR12.1 (B)
unnamed: R13.2, TR13.1 (B)
unnamed: R27.2, TR25.1 (B)
unnamed: R28.2, TR26.1 (B)
unnamed: R29.1, TR27.3 (B)
unnamed: R1.1, TR32.2 (C)
unnamed: TR70.3 (E), TR71.3 (E), TR72.3 (E), TR73.3 (E), TR80.3 (E), TR81.3 (E)
unnamed: TR82.3 (E), TR83.3 (E), TR95.3 (E), TR96.3 (E)
unnamed: R123.1, TR84.1 (D)
unnamed: R124.1, TR84.2 (G)
unnamed: R124.2, TR84.3 (S), TR87.3 (S)
unnamed: TY1.1 (K), TY2.1 (K), TY5.1 (K), TY6.1 (K)
unnamed: TY7.1 (K), TY8.1 (K), TY15.1 (K), TY16.1 (K)
unnamed: ICG1.14, WALZENANSTEUERUNG1.15

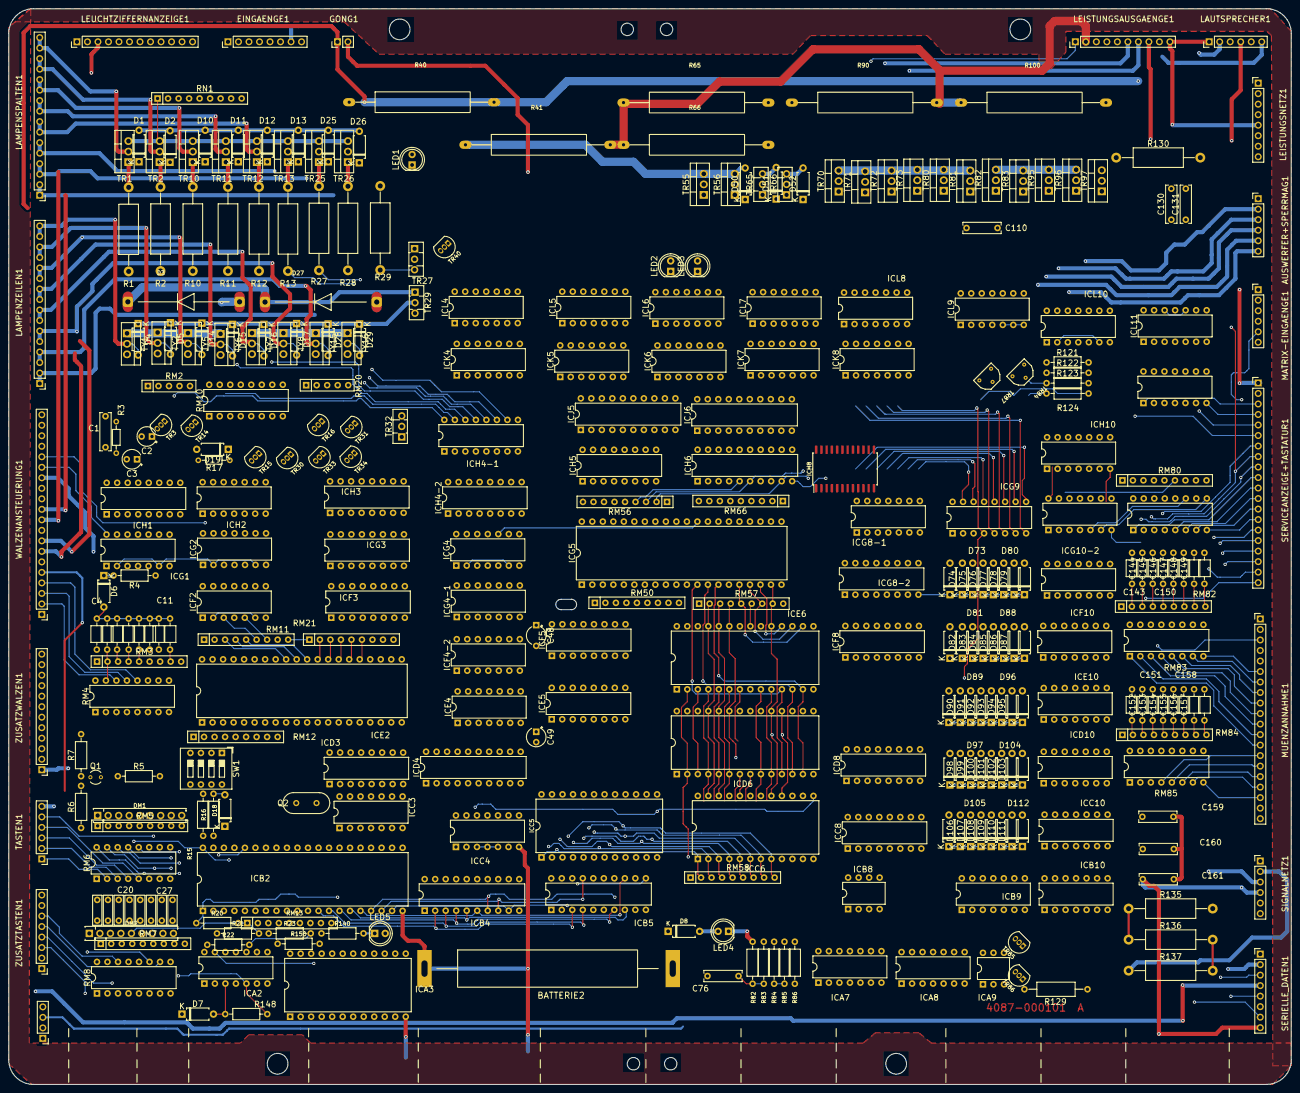
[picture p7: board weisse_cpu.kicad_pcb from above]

Board: 2 copper layers, 310.0 x 260.0 mm, 325 parts (0 on the bottom side), 196 nets.

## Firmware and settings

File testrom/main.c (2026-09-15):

/**
 * @file main.c
 * @brief Main program for adp Steuereinheit
 *
 * This program interacts with a type of German slot machine in use from the late 1980s-early 1990s
 *
 * The program initializes the controller in 16-bit display mode with encoded
 * keyboard scanning, then continuously scans for keyboard input and updates
 * the displays accordingly.
 *
 * @author stonedDiscord
 * @date 12.12.2025
 */

#include <stdint.h>
#include <stddef.h>

//#define EMULATOR

#if defined(BOARD4040)
#define I8279_IO    0x80
#define I8256_IO    0x90
#define RTC_ADD     0x6000
#pragma output REGISTER_SP = 0x53fc
#pragma output CRT_ORG_BSS = 0x5000
#include "hd146818.c"

#elif defined(BOARD4109)
#define I8279_IO    0x50
#define I8256_IO    0x60
#define RTC_IO      0x00
#pragma output REGISTER_SP = 0x9ff0
#pragma output CRT_ORG_BSS = 0x9000
#include "rtc62421.c"

#else // BOARD4087 default
#define I8279_IO    0x50
#define I8256_IO    0x60
#define RTC_ADD     0x9000
#pragma output REGISTER_SP = 0xc7f0
#pragma output CRT_ORG_BSS = 0xc000
#include "hd146818.c"
#endif

#include "8279.c"
#include "8256.c"

// RAM bounds for the RAM size self-test.
//   RAM_BASE      - first RAM address (matches CRT_ORG_BSS)
//   RAM_SCAN_MAX  - one past the last address to probe (kept below any MMIO)
//   RAM_STACK_TOP - top of the stack (matches REGISTER_SP); probes near here
//                   are skipped so the test never clobbers its own stack frame
#if defined(BOARD4040)
#define RAM_BASE      0x5000
#define RAM_SCAN_MAX  0x6000   // RTC is mapped at 0x6000
#define RAM_STACK_TOP 0x53fc

#elif defined(BOARD4109)
#define RAM_BASE      0x9000
#define RAM_SCAN_MAX  0xA000
#define RAM_STACK_TOP 0x9ff0

#else // BOARD4087 default
#define RAM_BASE      0xc000
#define RAM_SCAN_MAX  0x10000
#define RAM_STACK_TOP 0xc7f0
#endif

enum COUNTER_VALS {
    COUNTERS_START_SOUND = 0x01,
    COUNTERS_GONG        = 0x02,
    COUNTERS_MUTE        = 0x04,
    COUNTERS_UG          = 0x08,
    COUNTERS_DS          = 0x10,
    COUNTERS_US          = 0x20,
    COUNTERS_DM          = 0x40,
    COUNTERS_UM          = 0x80,
};

#include "track.c"

volatile struct rtc_state_t *rtc;

#define COINS       0x70
#define COUNTERS    0x71
#define SOUND       0x72

volatile bool timer3_flag = false;
volatile bool blink_flag = false;
bool date_edit_mode = false;
bool time_edit_mode = false;
int8_t selected_digit = -1;
int8_t menu_item = 0;

uint8_t sensor_ram[8];        // raw current sample
uint8_t sensor_prev[8];       // previous raw sample (for debounce)
uint8_t sensor_debounced[8];  // confirmed stable state
uint8_t sensor_baseline[8];   // boot "rest" state - presses are deviations from this
uint8_t pressed_prev[8];      // pressed state from previous scan (for edge detection)
uint8_t button_edge[8];       // bits that went pressed since last scan (rising edge)
uint8_t sensor_row = 0;

// Software blink: toggle blink_flag every BLINK_PERIOD main-loop iterations.
// Tune to taste - higher = slower blink. (Timer 5 ISR blink is not enabled.)
#define BLINK_PERIOD 25
uint16_t blink_counter = 0;

uint8_t money_display[8];
uint8_t service_display[8];

/**
 * @brief Enable Interrupts
 *
 * @param data Interrupt array
 */
void enable_interrupts() {
    __asm
        EI
    __endasm;
}

/**
 * @brief Disable Interrupts (8085 interrupt delivery off)
 */
void disable_interrupts() {
    __asm
        DI
    __endasm;
}

// timer2
void _8085_int1() {
    // unused
}
// timer3
void _8085_int3() {
    timer3_flag = false;
}
// tx int
void _8085_int5() {
    // unused
}
//timer5
void _8085_int7() {
    blink_flag = !blink_flag;
    // Keep this minimal - only hardware register operations
    set_timer5(250);
}

/**
 * @brief Keyboard/display controller interrupt handler RST65
 *
 * Currently a placeholder function.
 */
void _8085_int65() {
    //read_sensor_matrix();
}

void read_sensor_matrix() {
    for (uint8_t row = 0; row < 8; row++) {
        sensor_ram[row] = read_sram(row);
    }
}

/**
 * @brief Sample the button matrix at boot and remember the rest state
 *
 * Reads the sensor matrix twice and stores the result as the baseline.
 * At runtime a button counts as pressed when its debounced state differs
 * from this baseline, so the wiring polarity (active-high vs active-low)
 * is detected automatically per machine/emulator layout.
 *
 * @note A button physically held during boot becomes its own baseline and
 *       reads as released until it is released and pressed again.
 */
void calibrate_buttons() {
    read_sensor_matrix();
    for (uint8_t row = 0; row < 8; row++) {
        sensor_prev[row] = sensor_ram[row];
    }
    dumb_delay(50);
    read_sensor_matrix();
    for (uint8_t row = 0; row < 8; row++) {
        sensor_baseline[row]  = sensor_ram[row];
        sensor_debounced[row] = sensor_ram[row];
        sensor_prev[row]      = sensor_ram[row];
        pressed_prev[row]     = 0;   // nothing pressed relative to baseline yet
        button_edge[row]      = 0;
    }
}

/**
 * @brief Sample the button matrix with software debouncing
 *
 * Only bits that read the same as the previous scan are committed to the
 * debounced state, so a button must be stable for two consecutive scans
 * before its change is registered.
 */
void scan_buttons() {
    read_sensor_matrix();
    for (uint8_t row = 0; row < 8; row++) {
        uint8_t stable = ~(sensor_ram[row] ^ sensor_prev[row]); // bits unchanged this scan
        sensor_debounced[row] = (sensor_debounced[row] & ~stable)
                              | (sensor_ram[row]       &  stable);
        sensor_prev[row] = sensor_ram[row];

        // rising-edge: bits pressed now (vs baseline) that were not pressed last scan
        uint8_t pressed = sensor_debounced[row] ^ sensor_baseline[row];
        button_edge[row] = pressed & ~pressed_prev[row];
        pressed_prev[row] = pressed;
    }
}

/**
 * @brief Scan interrupt handler RST75
 *
 * Currently a placeholder function.
 */
void _8085_int75() {
    //refresh_display();
}

/**
 * @brief Sound interrupt handler RST55
 *
 * Currently a placeholder function.
 */
void _8085_int55() {
    // unused
    enable_interrupts();
}

/**
 * @brief Set the counter outputs via port 0x71
 * Used for the sound timer and mute control
 * @param data Data to write to the counter outputs
 */
void counter_out(uint8_t data) {
    uint8_t test = data;
    __asm
        OUT COUNTERS
    __endasm;
}

/**
 * @brief Set the sound note
 *
 * @param note Note value to play
 */
void set_sound(uint8_t note) {
    uint8_t test = note;
    __asm
        OUT SOUND
    __endasm;
}

void wait_timer3(uint8_t data) {
    timer3_flag = true;
    set_timer3(data); // Set timer value as needed
    enable_muart_interrupts(I8256_INT_L3);
    while (timer3_flag) {
        // Wait for timer3_flag to be cleared in interrupt
    }
}

/**
 * @brief Write data to indicator lamps
 *
 * @param line Lamp line number (0-7)
 * @param data Data to write to the lamp line
 */
void write_lamps(uint8_t line, uint8_t data) {
    kdc_cmd_out(I8279_WRITE_DISPLAY_RAM | (line & 7));
    kdc_data_out(data);
}

/**
 * @brief Write data to 7-segment display digits
 *
 * @param digit Digit position (0-7)
 * @param mon Digit on the money display
 * @param srv Digit on the service display
 */
void write_money(uint8_t digit, uint8_t value) {
    money_display[digit] = value;
}

void write_service(uint8_t digit, uint8_t value) {
    service_display[digit] = value;
}

void write_both(uint8_t digit, uint8_t value) {
    money_display[digit] = value;
    service_display[digit] = value;
}

void update_blink()
{
    if (date_edit_mode)
        display_rtc_date();

    if (time_edit_mode)
        display_rtc_time();

    // Clear all blink flags first
    for (uint8_t digit = 0; digit < 8; digit++) {
        money_display[digit] &= 0x0F;
        service_display[digit] &= 0x0F;
    }

    // Set the blink flag for the selected digit
    if (selected_digit >= 0 && selected_digit < 8) {
    money_display[selected_digit] |= 0xF0;
    service_display[selected_digit] |= 0xF0;
    }    
}

void refresh_display() {
    update_blink();
    kdc_cmd_out(I8279_WRITE_DISPLAY_RAM | I8279_RW_AUTO_INCREMENT | 8);
    for (uint8_t digit = 0; digit < 8; digit++) {

        // blink logic: if any of the upper nibbles are set, blink the digit
        uint8_t money_digit, service_digit;

        if ((money_display[digit] >> 4) && blink_flag)
           money_digit = 0xf0;
        else
           money_digit = money_display[digit] << 4;


        if ((service_display[digit] >> 4) && blink_flag)
           service_digit = 0x0f;
        else
           service_digit = service_display[digit] & 0x0f;
        
        kdc_data_out(money_digit | service_digit);
    }
}

/**
 * @brief Write a decimal number to the Serie display in the first 3 digits
 *
 * @param number Number to write to the lamp line
 */
void write_serie(uint8_t number) {
        // Convert data1 to decimal and display on digits 7-5
        uint8_t hundreds = number / 100;
        uint8_t tens = (number % 100) / 10;
        uint8_t ones = number % 10;
        
        write_money(7, hundreds);
        write_money(6, tens);
        write_money(5, ones);
}

/**
 * @brief Initialize the 8279 keyboard/display controller
 *
 * Sets up the controller in 16-bit display mode, left entry,
 * encoded keyboard mode with sensor matrix, configures clock divider,
 * clears all displays and FIFOs, and ends interrupt mode.
 *
 * @note Uses clock divider of 30 for the Merkur Board
 */
void init_kdc() {
    kdc_cmd_out(I8279_MODE_SET |
                I8279_MODE_DISPLAY_16BIT |
                I8279_MODE_DISPLAY_LE |
                I8279_MODE_KEYBOARD_ENCODED |
                I8279_MODE_KEYBOARD_SENSOR_MATRIX);
    set_kdc_clock(30);
    kdc_cmd_out(I8279_CLEAR | I8279_CLEAR_ALL);
    kdc_cmd_out(I8279_END_INTERRUPT);
}

/**
 * @brief Initialize the 8256 MUART
 * 
 * Configures the MUART for 4800 baud, 8 data bits, 1 stop bit,
 * enables receiver and transmitter, sets port modes, and enables interrupts.
 * 
 */
void init_muart() {
    __asm
        MVI A, I8256_CMD1_FRQ_1K | I8256_CMD1_8085 | I8256_CMD1_STOP_1 | I8256_CMD1_CHARLEN_8
        OUT I8256_CMD1
        MVI A, I8256_CMD2_SCLK_DIV3 | 5 //4800baud
        OUT I8256_CMD2
        MVI A, I8256_CMD3_RESET | I8256_CMD3_IAE | I8256_CMD3_RXE | I8256_CMD3_SET
        OUT I8256_CMD3
        MVI A, I8256_MODE_PORT2C_OO
        OUT I8256_MODE
        MVI A, 0x70
        OUT I8256_PORT1C
        MVI A, 0xff
        OUT I8256_PORT2
        MVI A, 0x30
        OUT I8256_PORT1
        MVI A, 0x08
        OUT I8256_INTEN
        MVI A, 0xBA
        OUT I8256_INTAD
    __endasm;
}

/**
 * @brief Initialize the 8255 PPI
 * 
 */
void init_ppi() {
    __asm
        MVI A, 0x80
        OUT 0x73
    __endasm;
}

/**
 * @brief Software delay function
 *
 * @param ms Number of milliseconds to delay
 * @note Timer 3 works at either 1kHz or 16kHz depending on configuration.
 *       This function assumes a 1kHz timer for millisecond delays.
 */
void delay(uint16_t ms) {
    uint16_t full_chunks = ms / 255;
    uint8_t remainder = ms % 255;

    // Wait for full 255ms chunks
    for (uint16_t i = 0; i < full_chunks; i++) {
        wait_timer3(255);
    }
    
    // Wait for the remaining milliseconds
    if (remainder > 0) {
        wait_timer3(remainder);
    }
}

/**
 * @brief Software delay function
 *
 * @param ms Number of milliseconds to delay
 * @note This is a simple busy-wait loop and not very precise
 */
void dumb_delay(uint16_t ms) {
    uint16_t i;
    for (i = 0; i < ms; i++) {
        for (uint8_t j = 0; j < 28; j++) {
        __asm
            NOP
            NOP
            NOP
        __endasm
        }
    }
}

void wait_tx_ready() {
    while ((read_status() & I8256_STATUS_TBE) == 0) {
        dumb_delay(1);
    }
}

/**
 * @brief Set data to be sent via MUART
 *
 * @param txdata Data to transmit
 */
void print_serial_char(uint8_t txdata) {
    wait_tx_ready();
    write_buffer(txdata);
}

uint8_t read_serial_char() {
    return read_buffer();
}

void print_string(const char* str) {
    while (*str) {
        print_serial_char(*str);
        str++;
    }
}

/**
 * @brief Print a byte as two hex digits over the serial port
 *
 * @param v Byte to print
 */
void print_hex8(uint8_t v) {
    const char hex[] = "0123456789ABCDEF";
    print_serial_char(hex[(v >> 4) & 0x0F]);
    print_serial_char(hex[v & 0x0F]);
}

void play_note(uint8_t note, uint8_t octave, uint8_t duration)
{
    uint8_t l_notedata = 0;
    l_notedata |= (note & 0x0F);
    l_notedata |= ((duration & 0x03) << 4);
    l_notedata |= ((octave & 0x03) << 6);    
    set_sound(l_notedata);
    counter_out(COUNTERS_START_SOUND);
    dumb_delay(1);
    counter_out(0);
}

void play_track()
{
    for (uint16_t i = 0; i < sizeof(track) / sizeof(track[0]); i++)
    {
        play_note(track[i].note, track[i].octave, track[i].duration);
        write_both(0, track[i].note);
        write_both(1, track[i].octave);
        write_both(2, track[i].duration);
        write_both(3, track[i].length);
        write_both(4, i);
        refresh_display();
        // Print lyric to serial port
        if (track[i].lyric != 0)
        {
            const char *lyric = track[i].lyric;
            print_string(lyric);
            print_string(" ");
        }

        dumb_delay(track[i].length * 3);
    }
}

/**
 * @brief Macro to define a button with row, column, and inversion
 *
 * @param row Row number (0-7)
 * @param col Column number (0-7)
 * @param inverted Inversion flag (0 or 1)
 */
#define BUTTON(row, col, inverted) (uint8_t)(((row & 0x07) << 4) | (col & 0x0F) | ((inverted & 0x01) << 7))

// Button definitions
#define RISK_LEFT  BUTTON(3, 1, 1)
#define STOP_MID   BUTTON(3, 3, 1)
#define RISK_RIGHT BUTTON(3, 0, 1)
#define RETURN     BUTTON(0, 3, 1)

// Servicetastatur
#define RESET      BUTTON(6, 7, 0)
#define DAUERLAUF  BUTTON(6, 6, 0)
#define SPIELZ     BUTTON(6, 5, 0)
#define SPEICHER   BUTTON(6, 4, 0)
#define HW_TEST    BUTTON(6, 3, 0)
#define AZQ        BUTTON(6, 2, 0)
#define FOUL       BUTTON(6, 1, 0)
#define GEWINN     BUTTON(6, 0, 0)

#define HOCH1      BUTTON(7, 7, 0)
#define RUNTER1    BUTTON(7, 6, 0)
#define HOCHS      BUTTON(7, 5, 0)
#define RUNTERS    BUTTON(7, 4, 0)
#define HOCH01     BUTTON(7, 3, 0)
#define RUNTER01   BUTTON(7, 2, 0)
#define MUENZ      BUTTON(7, 1, 0)
#define INIT       BUTTON(7, 0, 0)

/**
 * @brief Check the state of a button
 *
 * @param button Button identifier (row, column, and inversion flag)
 * @return bool State of the button (0 or 1)
 */
bool check_button(uint8_t button) {
    uint8_t row = (button >> 4) & 0x07;
    uint8_t mask = 1 << (button & 0x0F);

    // Pressed = debounced state deviates from the boot baseline.
    // Polarity is handled by calibration, so the inverted bit is ignored.
    return ((sensor_debounced[row] ^ sensor_baseline[row]) & mask) != 0;
}

/**
 * @brief Check whether a button was just pressed (rising edge)
 *
 * Returns true for one scan only, on the transition from released to pressed.
 * Use this for menu navigation so a single physical press = a single step.
 *
 * @param button Button identifier (row, column, and inversion flag)
 * @return bool true on the scan where the button became pressed
 */
bool check_button_edge(uint8_t button) {
    uint8_t row = (button >> 4) & 0x07;
    uint8_t mask = 1 << (button & 0x0F);

    return (button_edge[row] & mask) != 0;
}

/**
 * @brief Poll the return button so long-running tests can be cancelled
 *
 * Rescans the button matrix and reports a fresh press of the return / INIT
 * button. Call this inside any blocking loop in a self-test so the user can
 * always bail out instead of having to power-cycle.
 *
 * @return bool true if the user just pressed return
 */
bool test_cancelled() {
    scan_buttons();
    return check_button_edge(INIT) || check_button_edge(RETURN);
}

void display_rtc_date()
{
    uint8_t day = rtc_get_day();
    uint8_t month = rtc_get_month();
    uint8_t year = rtc_get_year();
    
    write_both(7, (day >> 4) & 0xF);
    write_both(6, day & 0xF);

    write_both(5, 0xff);

    write_both(4, (month >> 4) & 0xF);
    write_both(3, month & 0xF);

    write_both(2, 0xff);

    write_both(1, (year >> 4) & 0xF);
    write_both(0, year & 0xF);
}

// Function to display the time from the RTC
void display_rtc_time()
{
    uint8_t hours = rtc_get_hours();
    uint8_t minutes = rtc_get_minutes();
    uint8_t seconds = rtc_get_seconds();
    
    write_both(7, (hours >> 4) & 0xF);
    write_both(6, hours & 0xF);

    write_both(5, 0xff);

    write_both(4, (minutes >> 4) & 0xF);
    write_both(3, minutes & 0xF);

    write_both(2, 0xff);

    write_both(1, (seconds >> 4) & 0xF);
    write_both(0, seconds & 0xF);
}

/**
 * @brief Navigate to next valid digit (skip separator positions 2 and 5)
 */
void navigate_digit_next() {
    do {
        selected_digit++;
        if (selected_digit > 7)
            selected_digit = 7;
    } while (selected_digit == 5 || selected_digit == 2);
}

/**
 * @brief Navigate to previous valid digit (skip separator positions 2 and 5)
 */
void navigate_digit_prev() {
    do {
        selected_digit--;
        if (selected_digit < 0)
            selected_digit = 0;
    } while (selected_digit == 5 || selected_digit == 2);
}

/**
 * @brief Handle date edit mode
 */
void handle_date_edit_mode(bool buttonl, bool buttons, bool buttonr, bool buttonret) {
    if (buttonl) {
        navigate_digit_next();
        display_rtc_date();
        refresh_display();
        dumb_delay(200);
    } else if (buttonr) {
        navigate_digit_prev();
        display_rtc_date();
        refresh_display();
        dumb_delay(200);
    }

    if (buttons) {
        switch (selected_digit) {
            case 7: rtc_increment_day_tens(); break;
            case 6: rtc_increment_day_ones(); break;
            case 4: rtc_increment_month_tens(); break;
            case 3: rtc_increment_month_ones(); break;
            case 1: rtc_increment_year_tens(); break;
            case 0: rtc_increment_year_ones(); break;
        }
        display_rtc_date();
        refresh_display();
        dumb_delay(200);
    }

    if (buttonret) {
        date_edit_mode = false;
        // Clamp date values
        uint8_t day = rtc_get_day();
        uint8_t full_day = ((day >> 4) & 0xF) * 10 + (day & 0xF);
        if (full_day < 1) rtc_set_day(0x01);
        if (full_day > 31) rtc_set_day(0x31);
        
        uint8_t month = rtc_get_month();
        uint8_t full_month = ((month >> 4) & 0xF) * 10 + (month & 0xF);
        if (full_month < 1) rtc_set_month(0x01);
        if (full_month > 12) rtc_set_month(0x12);
        
        selected_digit = -1;
        display_rtc_date();
        refresh_display();
    }
}
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
int main(void) {
    init_kdc();
    init_muart();
    init_ppi();

#ifdef BOARD4109
    // RTC62421 is I/O mapped, not memory mapped - no pointer needed
#else
    rtc = (struct rtc_state_t *)RTC_ADD;
#endif
    rtc_init();  // Initialize RTC (24-hour format, start counting)

    print_string("Test ROM Initialized\n");

    calibrate_buttons();    // Sample button rest state for auto polarity detection

    _8085_int7();           // Initialize timer5 for blinking
    enable_interrupts();     // Enable interrupts - but handlers are now minimal!

    write_lamps(0, 0x16);   // light up pressable buttons
    write_lamps(3, 0xc0);   // return

    // Infinite loop to scan the keyboard
    while (1) {
        // Sample + debounce buttons - no interrupt protection needed since ISR is minimal
        scan_buttons();

        // Edge-triggered: one step per physical press (fixes navigation double-stepping)
        #ifdef EMULATOR // current mame on master has the risk buttons reversed
        bool buttonl = check_button_edge(RUNTER01);
        bool buttons = check_button_edge(GEWINN);
        bool buttonr = check_button_edge(HOCH1);
        bool buttonret = check_button_edge(INIT);
        #else
        bool buttonl = check_button_edge(RUNTER01) | check_button_edge(RISK_LEFT);
        bool buttons = check_button_edge(GEWINN) | check_button_edge(STOP_MID);
        bool buttonr = check_button_edge(HOCH1) | check_button_edge(RISK_RIGHT);
        bool buttonret = check_button_edge(INIT) | check_button_edge(RETURN);
        #endif

        if (check_button_edge(HW_TEST)) {
            menu_play_music();
        }
        if (check_button_edge(DAUERLAUF)) {
            menu_edit_date();
        }
        if (check_button_edge(FOUL)) {
            menu_edit_time();
        }

        // Mode handling
        if (date_edit_mode) {
            handle_date_edit_mode(buttonl, buttons, buttonr, buttonret);
        } else if (time_edit_mode) {
            handle_time_edit_mode(buttonl, buttons, buttonr, buttonret);
        } else {
            handle_normal_mode(buttonl, buttons, buttonr, buttonret);
        }

        if (read_status() & I8256_STATUS_RBF) {
            uint8_t rcv = read_serial_char();
            print_serial_char(rcv);
        }

        // Software blink: timer5 ISR is not enabled, so drive blink_flag here
        if (++blink_counter >= BLINK_PERIOD) {
            blink_counter = 0;
            blink_flag = !blink_flag;
        }

        // Always refresh display every loop - blink_flag is used for effects
        refresh_display();
    }
}

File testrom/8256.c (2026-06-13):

/**
 * @file 8256.h
 * @brief Header file for Intel 8256 I8256 controller interface
 *
 * @author stonedDiscord
 * @date 15.12.2025
 */
#ifndef HEADER_8256
#define HEADER_8256

#include <stdbool.h>

#ifndef I8256_IO
#error "Please set the I8256_IO base address before including this file."
#endif

#define I8256_CMD1          I8256_IO + 0x00
#define I8256_CMD2          I8256_IO + 0x01
#define I8256_CMD3          I8256_IO + 0x02
#define I8256_MODE          I8256_IO + 0x03
#define I8256_PORT1C        I8256_IO + 0x04
#define I8256_INTEN         I8256_IO + 0x05
#define I8256_INTAD         I8256_IO + 0x06
#define I8256_BUFFER        I8256_IO + 0x07
#define I8256_PORT1         I8256_IO + 0x08
#define I8256_PORT2         I8256_IO + 0x09
#define I8256_TIMER1        I8256_IO + 0x0a
#define I8256_TIMER2        I8256_IO + 0x0b
#define I8256_TIMER3        I8256_IO + 0x0c
#define I8256_TIMER4        I8256_IO + 0x0d
#define I8256_TIMER5        I8256_IO + 0x0e
#define I8256_STATUS        I8256_IO + 0x0f

// Function prototypes
void set_timer3(uint8_t data);
uint8_t read_timer3();
void set_timer5(uint8_t data);
uint8_t read_port1();
uint8_t read_port2();
void set_port1(uint8_t data);
void set_port2(uint8_t data);
void set_port1_control(uint8_t data);
void set_muart_mode(uint8_t data);
void enable_muart_interrupts(uint8_t data);
void arm_muart_interrupts(uint8_t data);
uint8_t read_status();
void write_buffer(uint8_t txdata);
uint8_t read_buffer();


#define I8256_CMD1_FRQ_16    0x00
#define I8256_CMD1_FRQ_1K    0x01
#define I8256_CMD1_8085      0x00
#define I8256_CMD1_8086      0x02
#define I8256_CMD1_BITI      0x04
#define I8256_CMD1_BRKI      0x08
#define I8256_CMD1_STOP_1    0x00
#define I8256_CMD1_STOP_15   0x10
#define I8256_CMD1_STOP_2    0x20
#define I8256_CMD1_STOP_075  0x30
#define I8256_CMD1_CHARLEN_8 0x00
#define I8256_CMD1_CHARLEN_7 0x40
#define I8256_CMD1_CHARLEN_6 0x80
#define I8256_CMD1_CHARLEN_5 0xC0

#define I8256_CMD2_SCLK_DIV5 0x00
#define I8256_CMD2_SCLK_DIV3 0x10
#define I8256_CMD2_SCLK_DIV2 0x20
#define I8256_CMD2_SCLK_DIV1 0x30
#define I8256_CMD2_ODD_PARITY  0x00
#define I8256_CMD2_EVEN_PARITY 0x40
#define I8256_CMD2_NO_PARITY   0x00
#define I8256_CMD2_PARITY      0x80

#define I8256_CMD3_RESET    0x01
#define I8256_CMD3_TBRK     0x02
#define I8256_CMD3_SBRK     0x04
#define I8256_CMD3_END      0x08
#define I8256_CMD3_NIE      0x10
#define I8256_CMD3_IAE      0x20
#define I8256_CMD3_RXE      0x40
#define I8256_CMD3_SET      0x80

#define I8256_MODE_PORT2C_II   0x00
#define I8256_MODE_PORT2C_IO   0x01
#define I8256_MODE_PORT2C_OI   0x02
#define I8256_MODE_PORT2C_OO   0x03
#define I8256_MODE_PORT2C_HI   0x04
#define I8256_MODE_PORT2C_HO   0x05
#define I8256_MODE_PORT2C_DNU  0x06
#define I8256_MODE_PORT2C_TEST 0x07
#define I8256_MODE_CT2_TMR  0x00
#define I8256_MODE_CT2_CNT  0x08
#define I8256_MODE_CT3_TMR  0x00
#define I8256_MODE_CT3_CNT  0x10
#define I8256_MODE_T5C      0x20
#define I8256_MODE_T24      0x40
#define I8256_MODE_T35      0x80

#define I8256_INT_L0        0x01
#define I8256_INT_L1        0x02
#define I8256_INT_L2        0x04
#define I8256_INT_L3        0x08
#define I8256_INT_L4        0x10
#define I8256_INT_L5        0x20
#define I8256_INT_L6        0x40
#define I8256_INT_L7        0x80

#define I8256_STATUS_FE     0x01
#define I8256_STATUS_OE     0x02
#define I8256_STATUS_PE     0x04
#define I8256_STATUS_BD     0x08
#define I8256_STATUS_TRE    0x10
#define I8256_STATUS_TBE    0x20
#define I8256_STATUS_RBF    0x40
#define I8256_STATUS_INT    0x80

/**
 * @brief Set Timer 3
 *
 * @param data Timer value
 */
void set_timer3(uint8_t data) {
    uint8_t test = data;
    __asm
        OUT I8256_TIMER3
    __endasm;
}

/**
 * @brief Read the current count of Timer 3
 *
 * @return uint8_t Current timer value (counts down)
 */
uint8_t read_timer3() {
    uint8_t out=0xaa;
    __asm
        POP HL
        IN I8256_TIMER3
        MOV L,A
        PUSH HL
    __endasm;
    return out;
}

/**
 * @brief Set Timer 5
 *
 * @param data Timer value
 */
void set_timer5(uint8_t data) {
    uint8_t test = data;
    __asm
        OUT I8256_TIMER5
    __endasm;
}

/**
 * @brief Read data from the 8256 MUART's Port 1
 *
 * @return uint8_t Data read from port
 */
uint8_t read_port1() {
    uint8_t out=0xaa;
    __asm
        POP HL
        IN I8256_PORT1
        MOV L,A
        PUSH HL
    __endasm;
    return out;
}

/**
 * @brief Read data from the 8256 MUART's Port 2
 * @return uint8_t Data read from port
 */
uint8_t read_port2() {
    uint8_t out=0xaa;
    __asm
        POP HL
        IN I8256_PORT2
        MOV L,A
        PUSH HL
    __endasm;
    return out;
}

/**
 * @brief Write data to the 8256 MUART's Port 1
 * @param data Value to drive on Port 1 (pins configured as outputs)
 */
void set_port1(uint8_t data) {
    uint8_t test = data;
    __asm
        OUT I8256_PORT1
    __endasm;
}

/**
 * @brief Write data to the 8256 MUART's Port 2
 * @param data Value to drive on Port 2 (pins configured as outputs)
 */
void set_port2(uint8_t data) {
    uint8_t test = data;
    __asm
        OUT I8256_PORT2
    __endasm;
}

/**
 * @brief Set the Port 1 direction control register
 * @param data Per-pin direction mask (1 = input, 0 = output)
 */
void set_port1_control(uint8_t data) {
    uint8_t test = data;
    __asm
        OUT I8256_PORT1C
    __endasm;
}

/**
 * @brief Write the MODE register (Port 2 direction + counter/timer config)
 * @param data Mode byte (see I8256_MODE_* defines)
 */
void set_muart_mode(uint8_t data) {
    uint8_t test = data;
    __asm
        OUT I8256_MODE
    __endasm;
}

/**
 * @brief Enable Interrupts
 *
 * @param data Interrupt array
 */
void enable_muart_interrupts(uint8_t data) {
    uint8_t test = data;
    __asm
        OUT I8256_INTEN
        EI
    __endasm;
}

/**
 * @brief Set the MUART interrupt-enable mask WITHOUT enabling 8085 delivery
 *
 * Same as enable_muart_interrupts() but omits the EI, so the chip will latch
 * its interrupt request (visible in the status INT bit) without the CPU ever
 * vectoring to an ISR. Use this to poll for a timer interrupt safely.
 *
 * @param data Interrupt enable mask
 */
void arm_muart_interrupts(uint8_t data) {
    uint8_t test = data;
    __asm
        OUT I8256_INTEN
    __endasm;
}

/**
 * @brief Read status from the 8256 MUART
 *
 * @return uint8_t Status byte
 */
uint8_t read_status() {
    uint8_t out=0xaa;
    __asm
        POP HL
        IN I8256_STATUS
        MOV L,A
        PUSH HL
    __endasm;
    return out;
}

/**
 * @brief Set data to be sent via MUART
 *
 * @param txdata Data to transmit
 */
void write_buffer(uint8_t txdata) {
    uint8_t test = txdata;
    __asm
        OUT I8256_BUFFER
    __endasm;
}

uint8_t read_buffer() {
    uint8_t out=0xaa;
    __asm
        POP HL
        IN I8256_BUFFER
        MOV L,A
        PUSH HL
    __endasm;
    return out;
}

#endif

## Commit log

2022-08-11 project file
    [weisse_cpu.kicad_pcb, weisse_cpu.kicad_sch]
2022-08-12 lampen ausgänge
    [weisse_cpu.kicad_sch]
2022-08-19 footprints und platine
    [weisse_cpu.kicad_pcb, weisse_cpu.kicad_sch]
2022-08-19 add a bunch of traces
    [weisse_cpu.kicad_pcb]
2023-08-09 move transistors down
    [weisse_cpu.kicad_pcb]
2023-08-09 move connectors
    [weisse_cpu.kicad_pcb]
2023-08-09 move holes
    [weisse_cpu.kicad_pcb]
2023-08-10 add eeprom
    [weisse_cpu.kicad_pcb, weisse_cpu.kicad_sch]
2023-08-10 new photo and new holes
    [weisse_cpu.kicad_pcb]
2023-08-11 mirror board
    [weisse_cpu.kicad_pcb]
2023-08-11 mehr anschluss
    [weisse_cpu.kicad_pcb, weisse_cpu.kicad_sch]
2023-08-11 3d fix
    [weisse_cpu.kicad_pcb]
2023-08-11 3d zoom
    [weisse_cpu.kicad_pcb]
2023-08-11 more zoom
    [weisse_cpu.kicad_pcb]
2023-08-11 zoom again
    [weisse_cpu.kicad_pcb]
2023-08-11 zoom out
    [weisse_cpu.kicad_pcb, weisse_cpu.kicad_sch]
2023-08-11 fill got lost again
    [weisse_cpu.kicad_pcb, weisse_cpu.kicad_sch]
2023-08-13 suqiggly lines
    [weisse_cpu.kicad_pcb]
2023-08-17 rtx 4060
    [weisse_cpu.kicad_pcb, weisse_cpu.kicad_sch]
2023-08-22 12v cap
    [weisse_cpu.kicad_pcb, weisse_cpu.kicad_sch]
2023-09-05 power resistors
    [weisse_cpu.kicad_pcb, weisse_cpu.kicad_sch]
2023-09-05 add transistors
    [weisse_cpu.kicad_sch]
2023-09-05 big resistor
2023-09-06 hab vergessen was das war
    [weisse_cpu.kicad_pcb]
2023-09-07 resistor packs
    [weisse_cpu.kicad_pcb, weisse_cpu.kicad_sch]
2023-09-12 neue teile
    [weisse_cpu.kicad_pcb, weisse_cpu.kicad_sch]
2023-09-12 big one
    [weisse_cpu.kicad_pcb, weisse_cpu.kicad_sch]
2023-09-13 batterie und so
    [weisse_cpu.kicad_sch]
2023-09-15 widerstand ist zwecklos
    [weisse_cpu.kicad_sch]
2023-09-24 mehr traces
    [weisse_cpu.kicad_sch]
2024-08-01 align to grid
    [weisse_cpu.kicad_sch]
2024-10-07 bringt nix mehr mit aktuellem kicad
2024-11-01 fix rom
    [weisse_cpu.kicad_sch]
2024-11-26 tr verschieben
    [weisse_cpu.kicad_sch]
2025-03-26 glaube sound
    [weisse_cpu.kicad_sch]
2025-06-25 rom ram
    [weisse_cpu.kicad_sch]
2025-07-02 sound und rl-sl
    [weisse_cpu.kicad_sch]
2025-07-02 sound runter
    [weisse_cpu.kicad_sch]
2025-07-04 m1a liw in out
    [weisse_cpu.kicad_sch]
2025-07-06 jumper 1/5?
    [weisse_cpu.kicad_sch]
2025-07-12 wd rw
    [weisse_cpu.kicad_sch]
2025-07-19 sound data
    [weisse_cpu.kicad_sch]
2025-08-08 jumper 2
    [weisse_cpu.kicad_sch]
2025-09-09 lampen tester
    [tester.kicad_pcb, tester.kicad_sch]
2025-09-24 led tester
    [tester.kicad_pcb, tester.kicad_sch]
2025-12-07 segment servicetastatur
    [weisse_cpu.kicad_sch]
2025-12-12 switch to z88dk
2025-12-14 20v 40v
    [weisse_cpu.kicad_sch]
2025-12-21 liz in
    [weisse_cpu.kicad_sch]
2025-12-21 ton freq
    [ton.ods]
2025-12-22 timer values
    [weisse_cpu.kicad_sch]
2025-12-22 timer simulation
    [stimer.kicad_pcb, stimer.kicad_sch]
2025-12-24 calibrated to roughly a second
2025-12-26 new track
2026-01-11 use timer3 for timing
2026-01-12 track function
2026-01-13 fix warnings because of brackets
    [main.c]
2026-01-13 snake case
2026-01-15 fix CI build interrupts
    [main.c]
2026-01-15 return button
2026-01-16 button indicators
2026-01-20 label formen
    [weisse_cpu.kicad_sch]
2026-02-21 old board io
2026-04-11 diode gedreht
    [weisse_cpu.kicad_sch]
2026-04-11 rand rechts
    [weisse_cpu.kicad_sch]
2026-04-12 fix some issues, still broken
    [main.c]
2026-04-12 board name
2026-04-13 no timer3 for now
2026-04-19 grosser ram
    [weisse_cpu.kicad_sch]
2026-06-12 timer test
2026-06-16 wheel test
